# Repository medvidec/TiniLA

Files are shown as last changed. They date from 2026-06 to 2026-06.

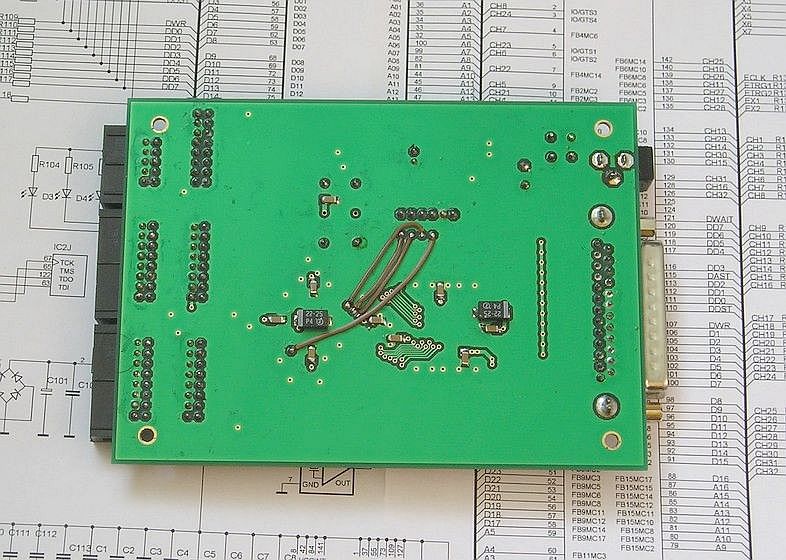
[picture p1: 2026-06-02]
docs/minila_bot_jtag_connection.jpg

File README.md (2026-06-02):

# TiniLA
Tiny logic analyzer based on XC95144XL and 128kx32 bit SRAM with USB interface. TiniLA name is derived from the bigger brother MiniLA.

## TiniLA Features
  * 32 channels 
  * 128 kilosamples per channel 
  * maximum sampling frequency 20MHz 
  * external clock 
  * trigger for first 6 input only - D0-D5 
  * no pretrigger, no posttrigger 
  * external trigger possible 
  * GUI supports FT2232 interface __only__

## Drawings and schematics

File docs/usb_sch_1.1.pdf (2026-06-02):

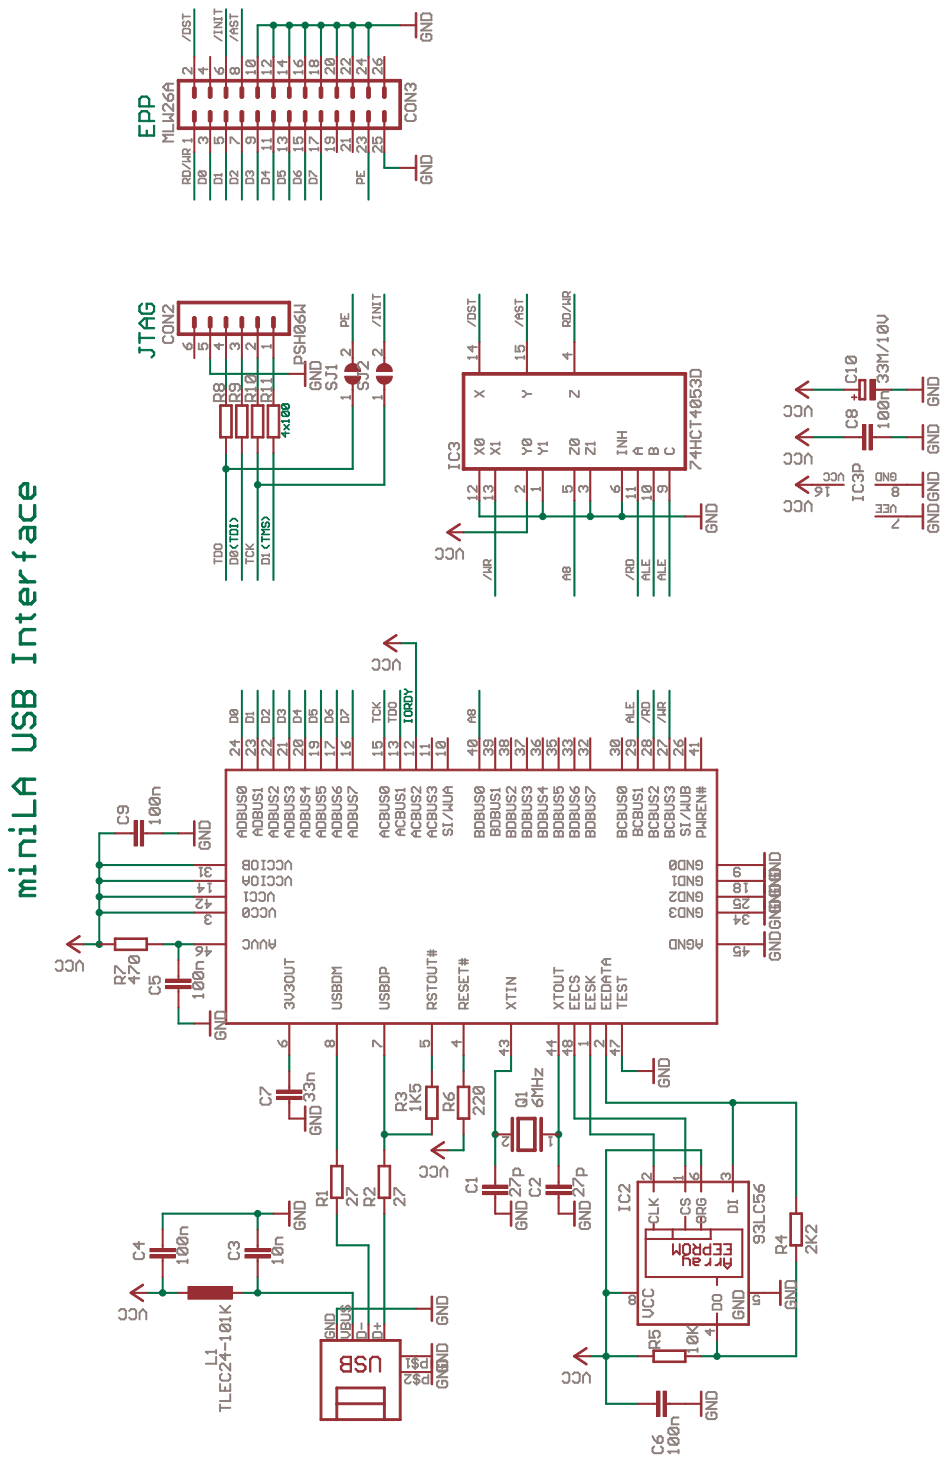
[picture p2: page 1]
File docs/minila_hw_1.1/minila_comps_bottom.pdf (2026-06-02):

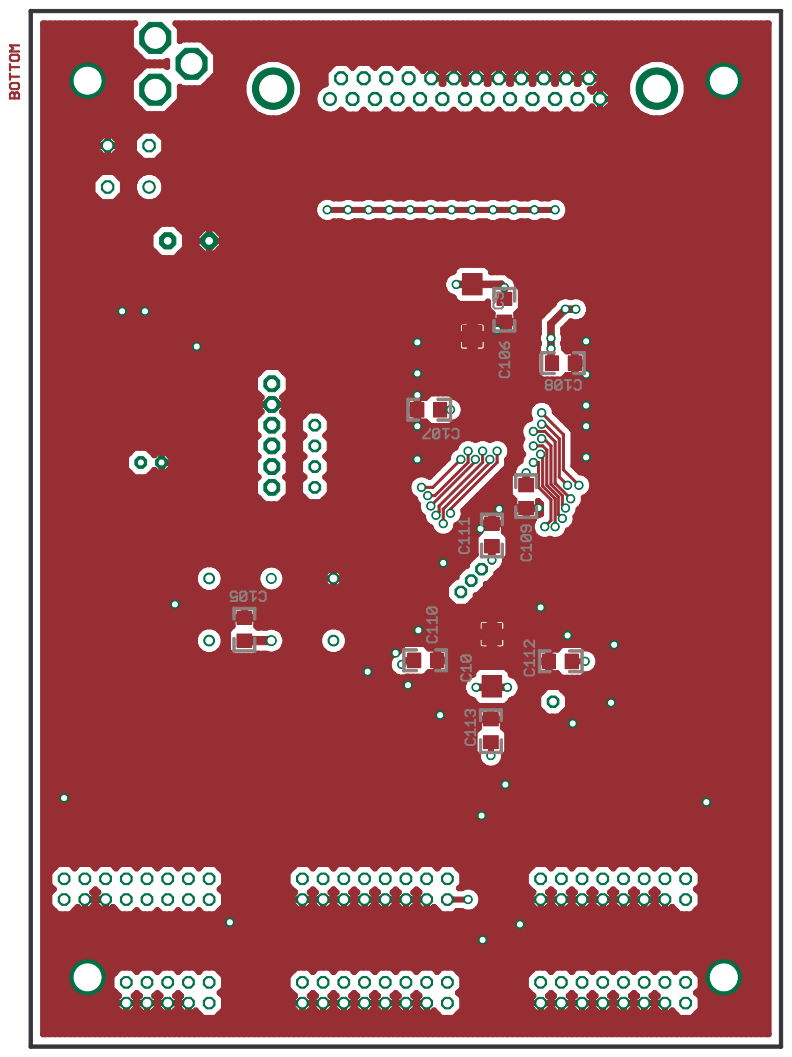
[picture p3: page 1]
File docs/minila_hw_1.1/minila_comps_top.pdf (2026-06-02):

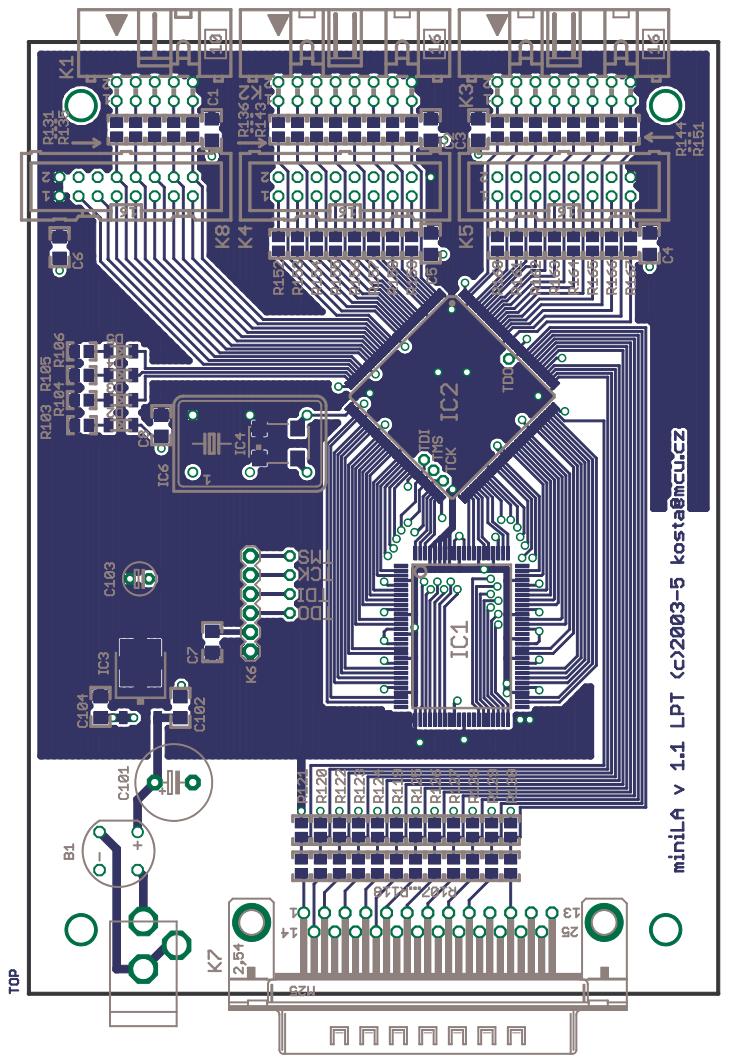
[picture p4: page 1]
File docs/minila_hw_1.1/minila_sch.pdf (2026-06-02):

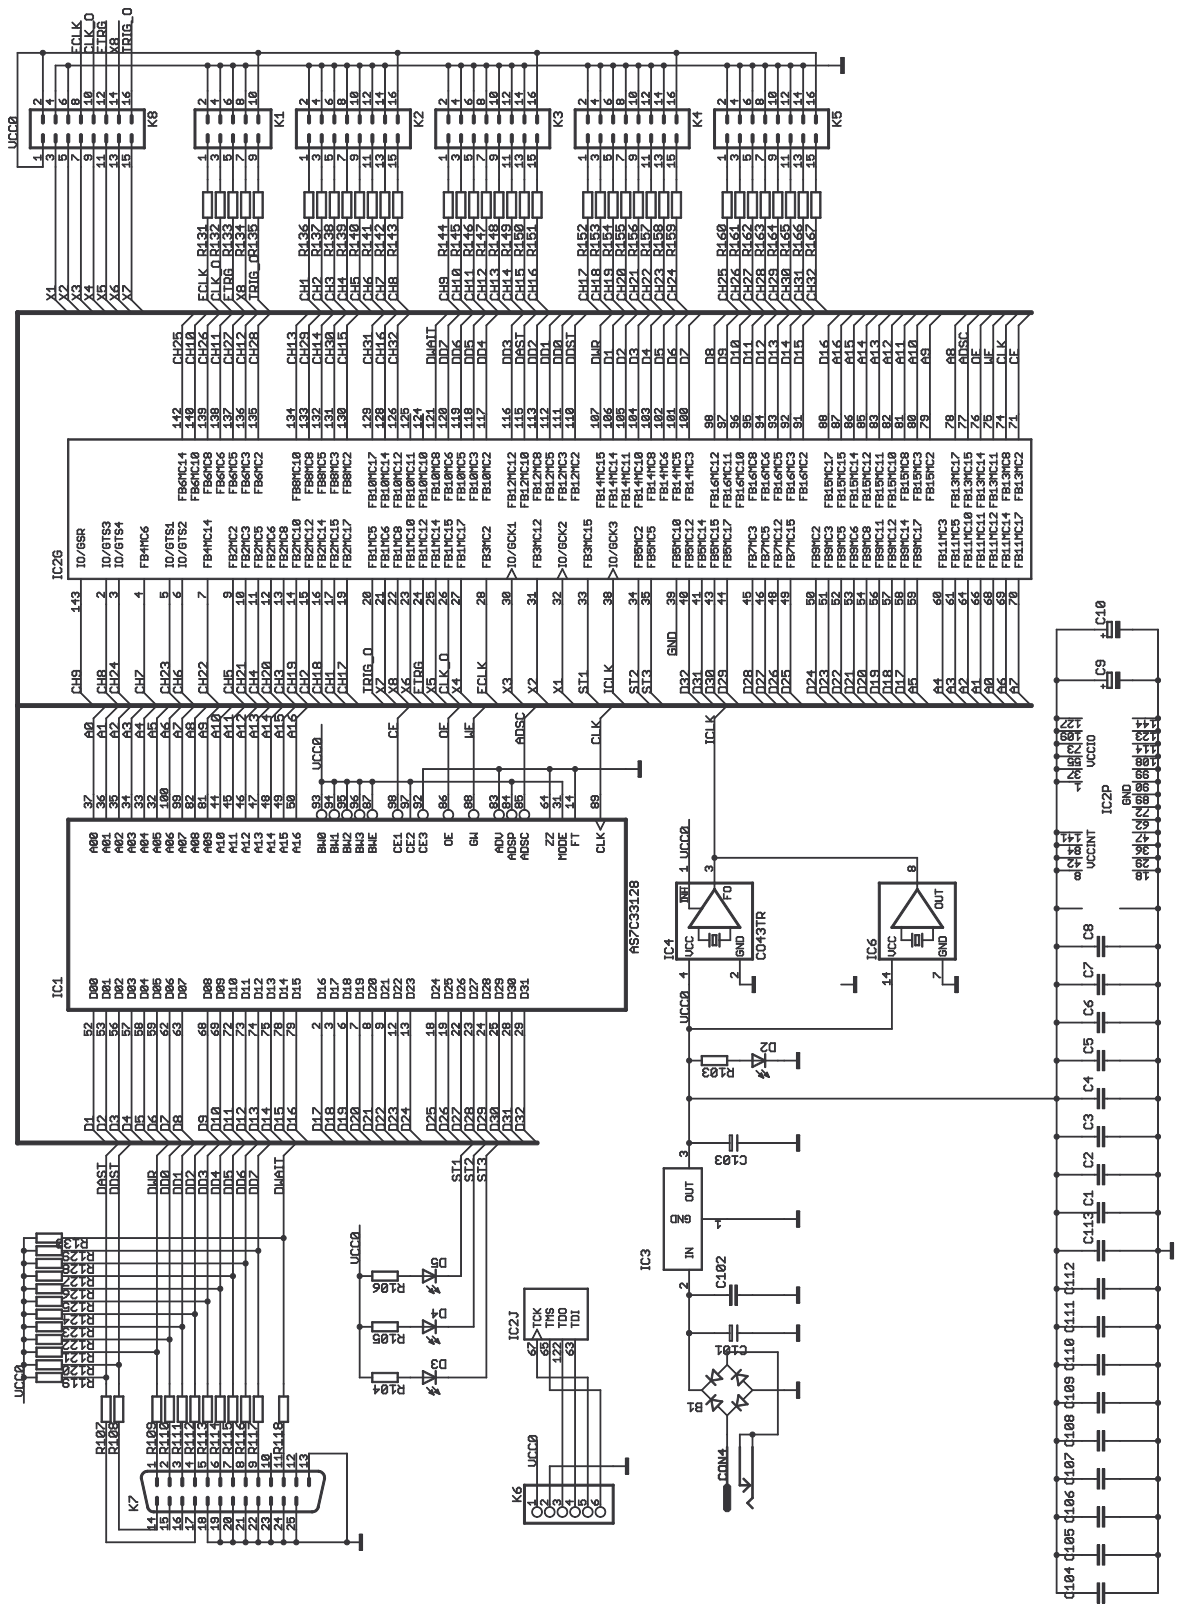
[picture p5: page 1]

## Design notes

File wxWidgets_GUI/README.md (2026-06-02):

# GUI in wxWidgets
GUI was redesigned in June 2026 however still using wxWidgets version 2.8.12.

Compilation confirmed in MinGW 5.1.6 on Windows 10.
 * mingw32-make -f Makefile.gcc

## ToDo:
 * cleanup - remove Config-Port menu as d2xx_open uses the usb description
 * Print waveform

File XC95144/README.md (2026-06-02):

# TiniLA protocol

## version 2010-03-07

TiniLA GUI uses FT2232 interface only !

## EPP registers' map

    Address          Write               Read
    0x0         Control register    Data register
    0x1         Trigger value      Status register
    0x2         Trigger mask     Address in SRAM 8..1
    0x3         Time base        Address in SRAM 16..9

## Reg description - write

###         Control register

    D7 - RUN - data acqusition start
    D6 - CLR - TiniLA reset
    D5 - SRAMCNTR_CLEAR - SRAM address counter reset
    D4 - AUTO_INC - sets autoincrement and rtead the first sample
    D3 - STOP - data acqusition stop
    D2 - FALLEDGE - falling edge sampling
    D1-D0 - BYTESEL - not necessary, resetting is enough

###      Trigger value

    D6-D0 - trigger level

###      Trigger mask

    D6-D0 - '1' means that the trigger value is checked

###      Time base - including ext trigger enable

    D7 - ext trigger level
    D6 - '1' - ext trigger enable
    D3-D0 - time base settings

## Reg description - read

###         Data register

    D7-D0 - acquired data
          - most significant byte of 32-bit word goes first

###       Status register

    D7 - DONE - end of acquisition
    D6 - RUN - TiniLA is running
    D5 - CLR - TiniLA in reset
    D4 - TRIG - trigger condition fulfilled
    D3 - SRAM_A0 - Bit 0 of the SRAM address
    D2-D0 - FW_REV - firmware revision - current is "001"

## TiniLA recommended command sequence

The current command sequence is in the code. Below is the old one.

    CTRL_REG <=  "01000000" -- Reset
    CTRL_REG <=  "00000000" -- Reset off
    TIMEB_REG <= "00000010" -- Time base settings
    TRVAL_REG <= "01010101" -- Trigger value settings
    TRMSK_REG <= "00011111" -- Trigger mask settings
    CTRL_REG <=  "01000000" -- Reset
    CTRL_REG <=  "10000000" -- Run the acquisition

    wait until STATUS_REG(7) = '1'

    CTRL_REG <=  "00010000" -- autoincrement
    read 4 bytes
    until STATUS_REG(3) = '0'
    read 4 bytes - 0x..FE
    read 4 bytes - 0x..FF - this is bug in CPLD
